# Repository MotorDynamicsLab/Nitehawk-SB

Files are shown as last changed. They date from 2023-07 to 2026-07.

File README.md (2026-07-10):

# Nitehawk-SB

This is the repo for Nitehawk-SB v1. The information for the updated version can be found here https://github.com/MotorDynamicsLab/Nitehawk-SB-V2.

Nitehawk is a toolhead PCB with a RP2040 MCU, TMC2209, Accelerometer all integrated into one board. The form factor is based on HartK’s two piece stealthburner toolhead PCB but with some minor changes. 

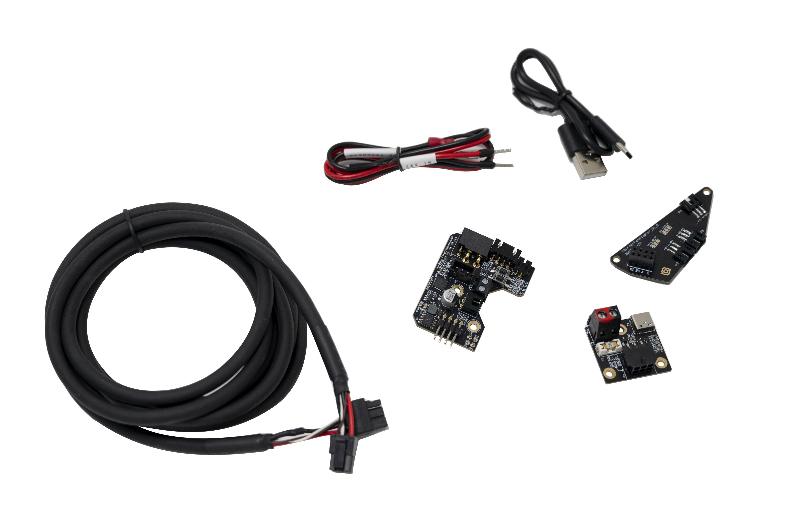
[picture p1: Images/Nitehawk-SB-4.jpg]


## Features

- Greatly simplified wiring, a single wire runs through the drag chain or in an umbilical setup. No additional breakout cables needed.
- Based on Klipper USB, no additional hardware or software setup compared to CAN.
- Tachometer enabled fan ports (PCF and HEF), allowing for fan speed detection.
- Integrated accelerometer for convenient input-shaping.

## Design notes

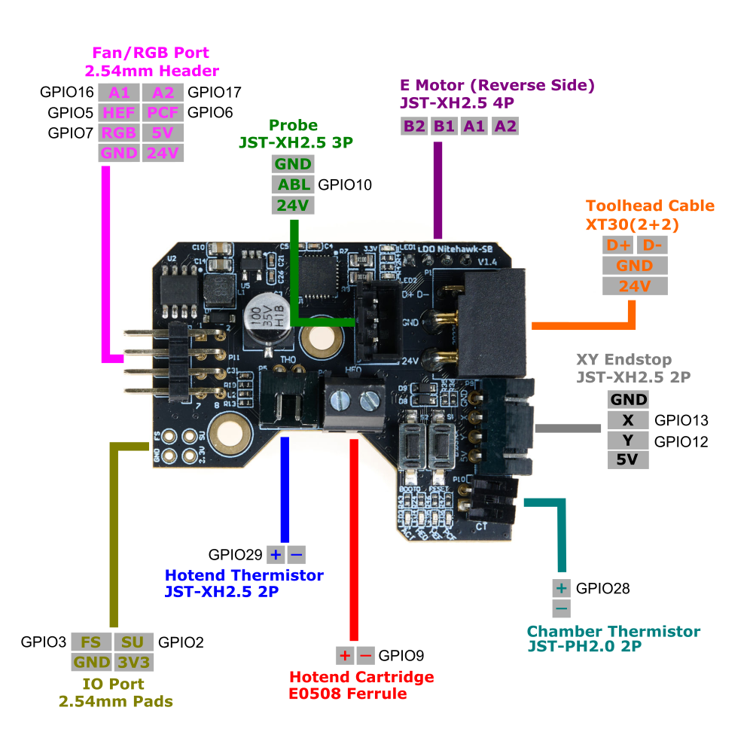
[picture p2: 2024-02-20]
Images/nhsb_pcb_pinout.png

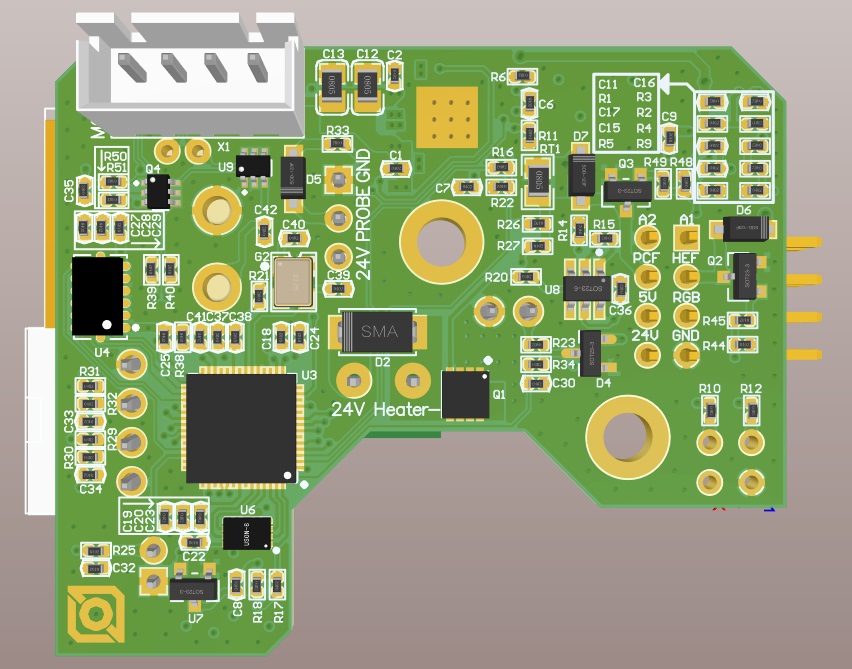
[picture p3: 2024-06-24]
Hardware/Nitehawk-SB_V1.5_3D Layout Bottom.jpg

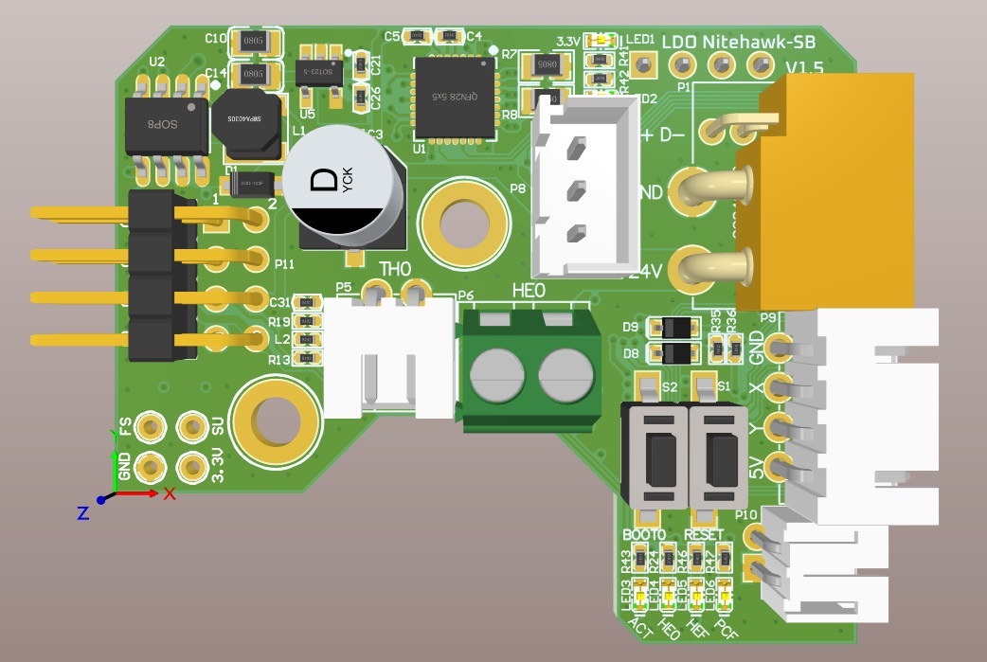
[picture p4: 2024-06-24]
Hardware/Nitehawk-SB_V1.5_3D Layout Top.jpg

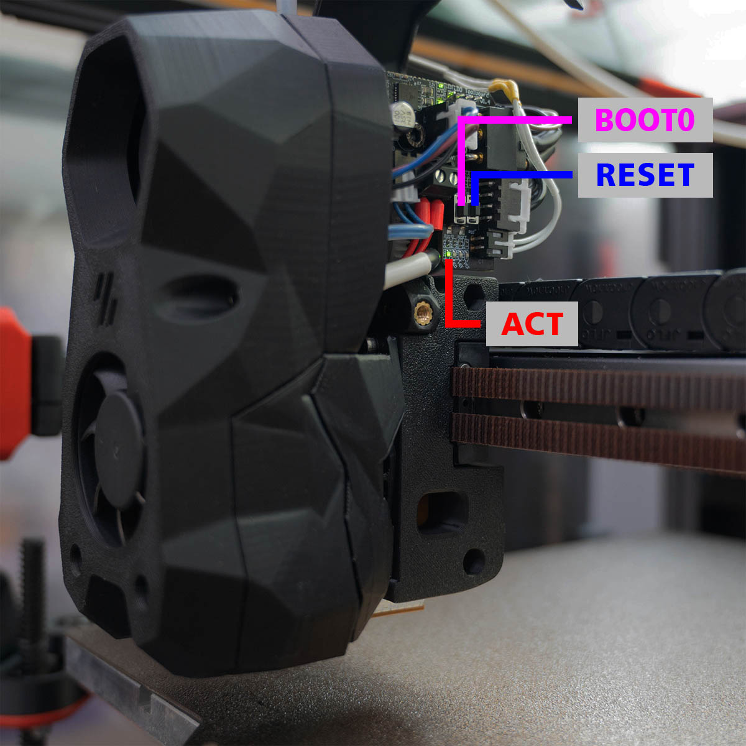
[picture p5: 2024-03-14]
Images/nitehawk_buttons.jpg

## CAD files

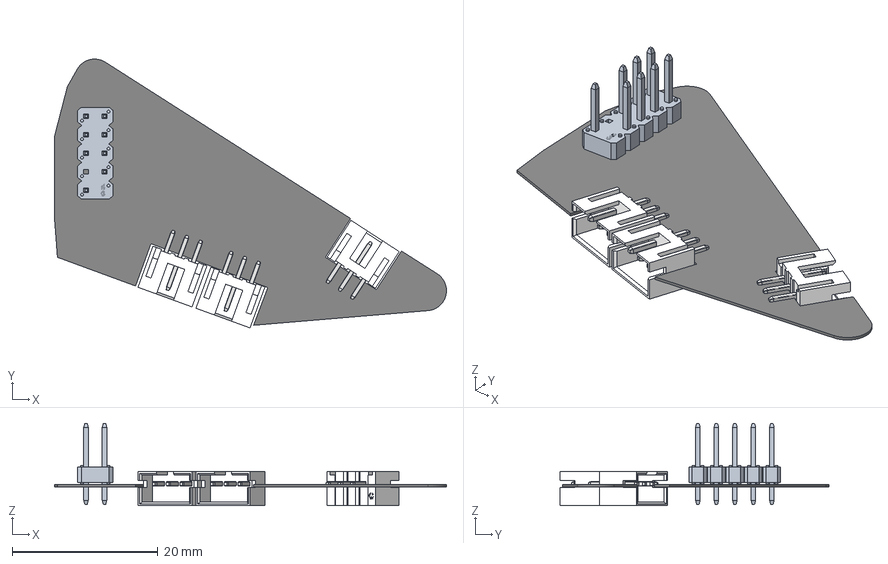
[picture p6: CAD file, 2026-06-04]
CAD/StealthBurner_Fan_Adapter_PCB.step
53.8 x 36.9 x 11.3 mm
PH2.0-LI-ӽ½ x 9
PH2.0-LI-3P x 3
LOGOԲ0.25 x 3
SBurnerFanAdapter 1.2.1
SBurnerFanAdapter_PCB

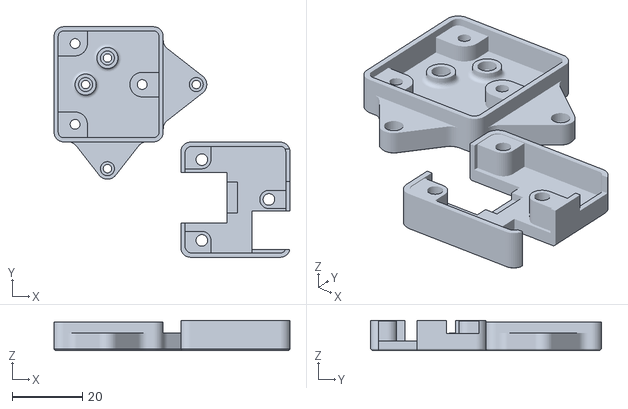
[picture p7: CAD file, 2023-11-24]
STLs/usb_adapter_mount.stl
67.2 x 65.6 x 8.60

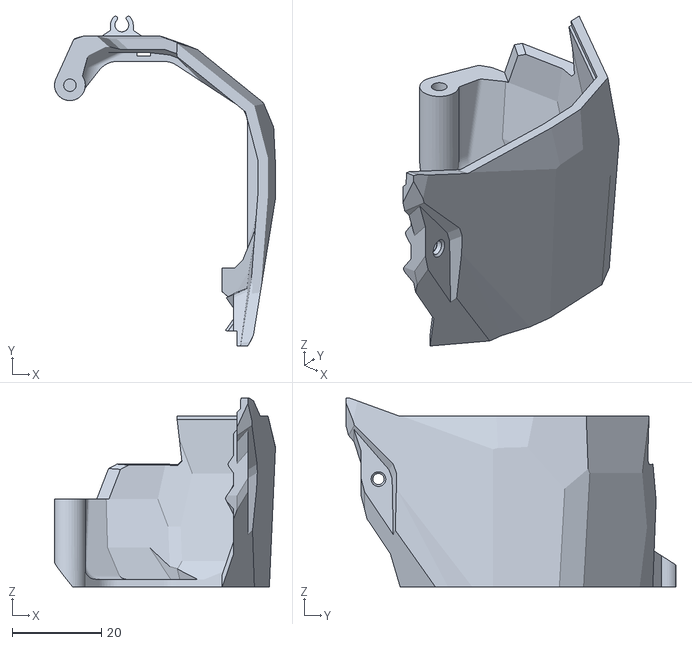
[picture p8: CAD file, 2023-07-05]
STLs/cw2_captive_pcb_cover.stl
49.5 x 73.8 x 42.2

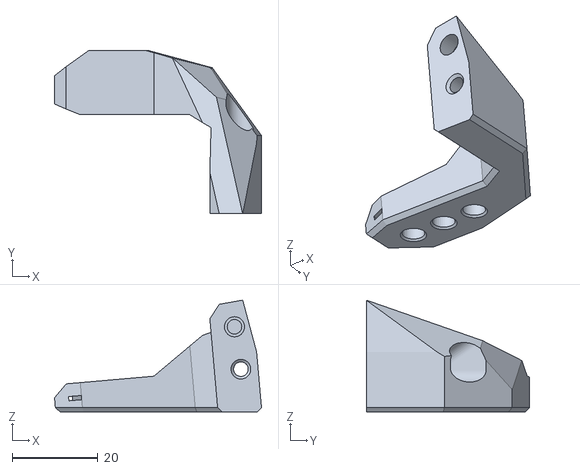
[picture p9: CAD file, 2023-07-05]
STLs/cw2_chain_anchor_tilted.stl
48.3 x 38.1 x 26.0

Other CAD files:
STLs/CW2 Captive PCB Cover.f3d
STLs/CW2 Chain Anchor Tilted.f3d
STLs/USB Adapter Mount.f3d

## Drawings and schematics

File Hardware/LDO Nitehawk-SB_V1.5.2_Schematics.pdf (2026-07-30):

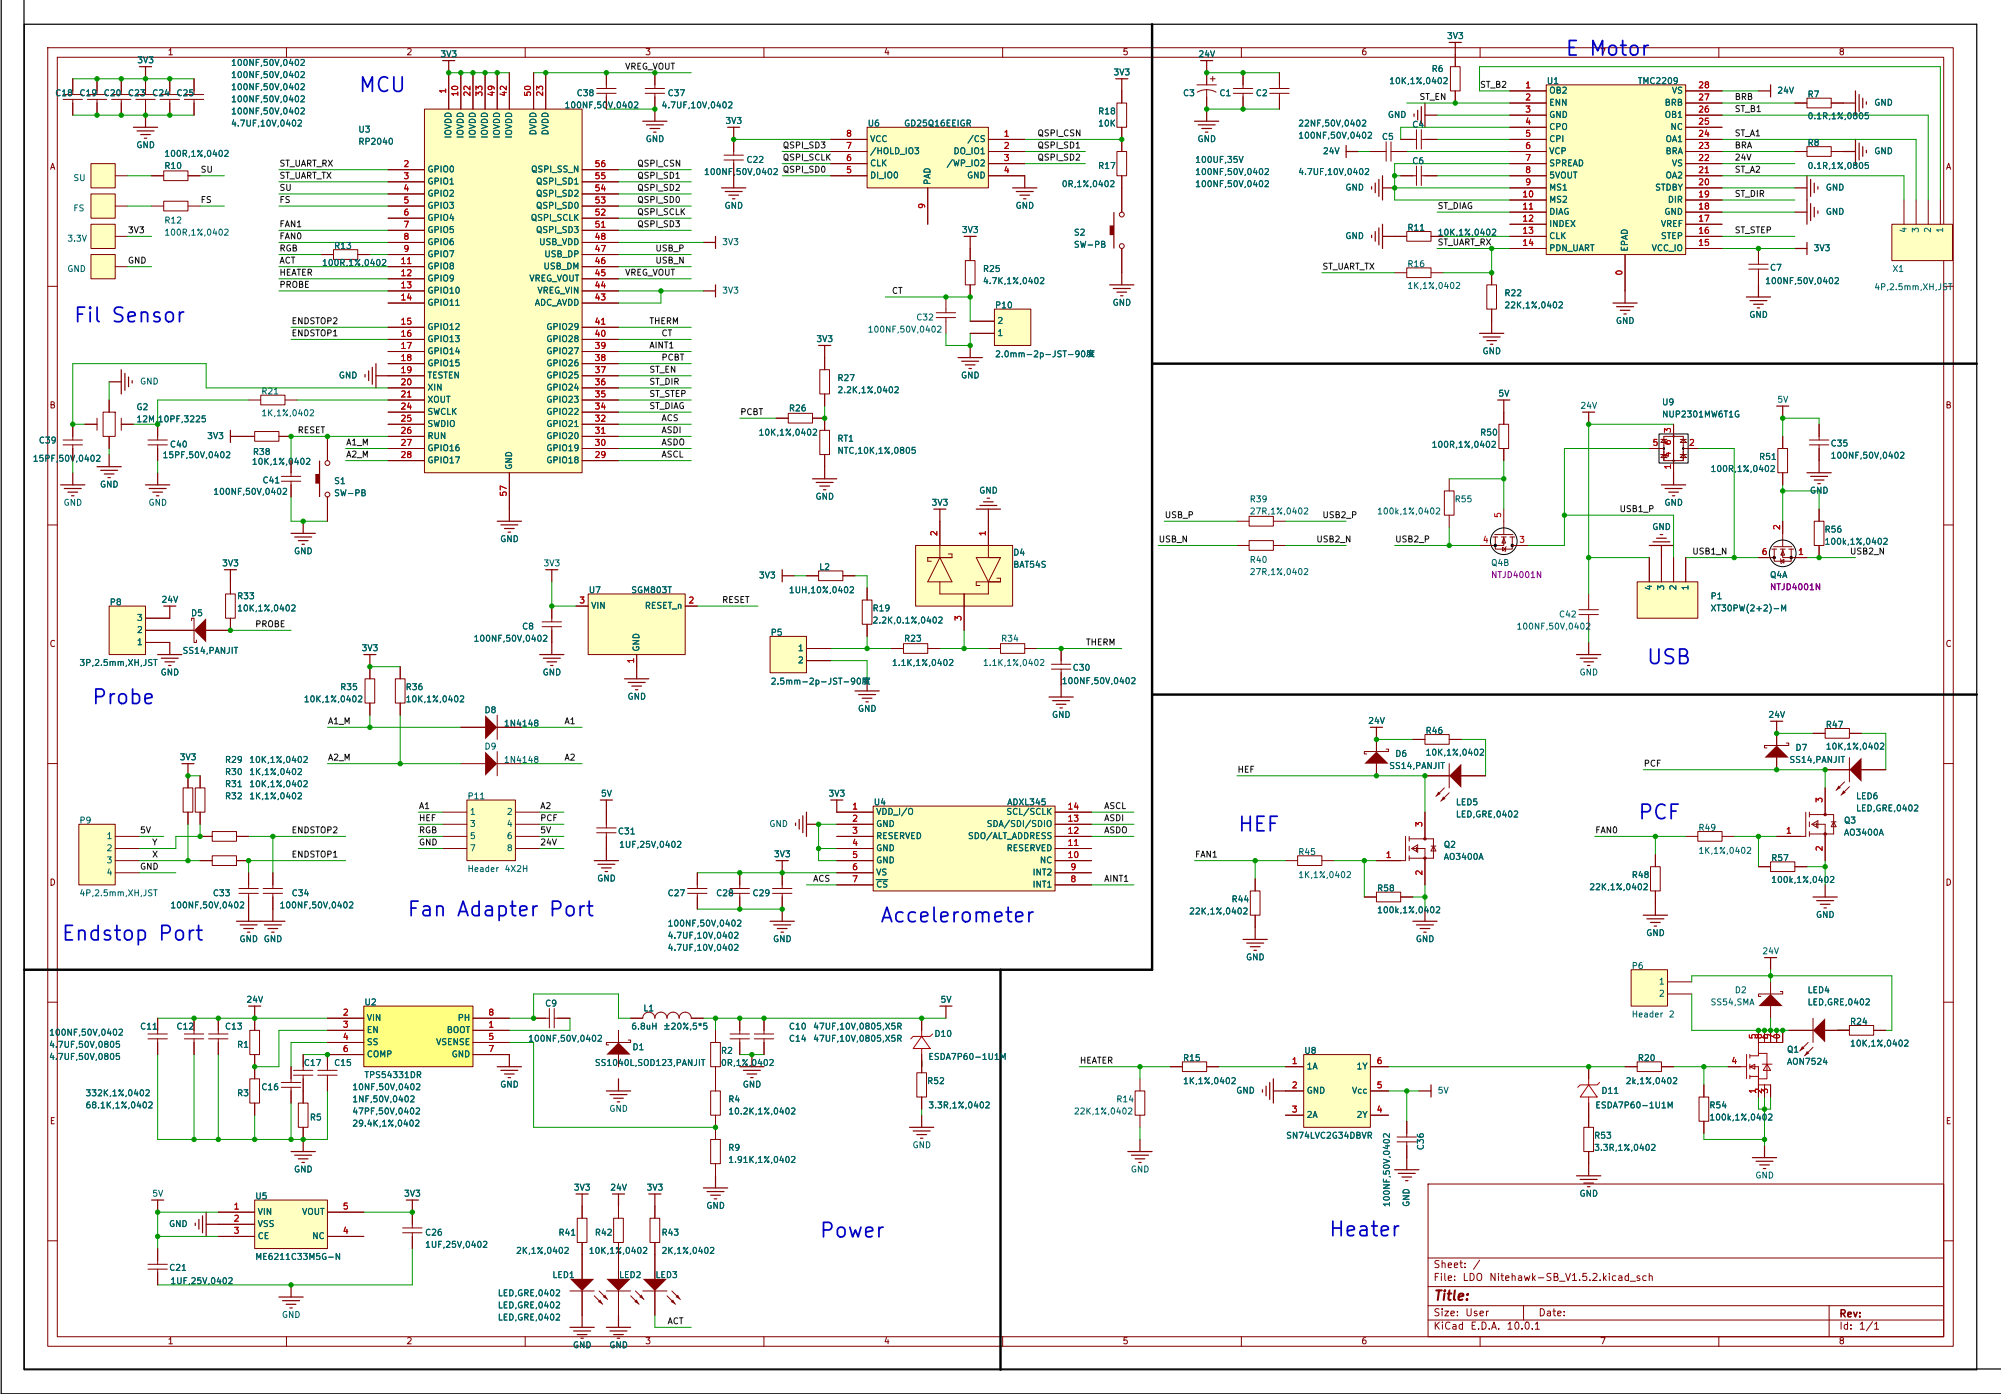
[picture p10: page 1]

RESERVED OR EXPRESS OR IMPLIED WARANTEE GIVEN. Fil Sensor

ENN 2 GND 3 CPO 4 CPI 5 | 26 BRB

APPROVALS PCB DWG: CHK: PCF

Size: User | Rev:
KiCad E.D.A. 10.0.1 | Id: 1/1

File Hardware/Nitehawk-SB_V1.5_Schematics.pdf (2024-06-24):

VCC_IO | 15 STEP | 16 VREF | 17 GND | 18 DIR | 19 STDBY | 20 OA2 | 21 VS | 22 BRA | 23 OA1 | 24 NC | 25 OB1 | 26 BRB | 27 VS | 28

# E Motor

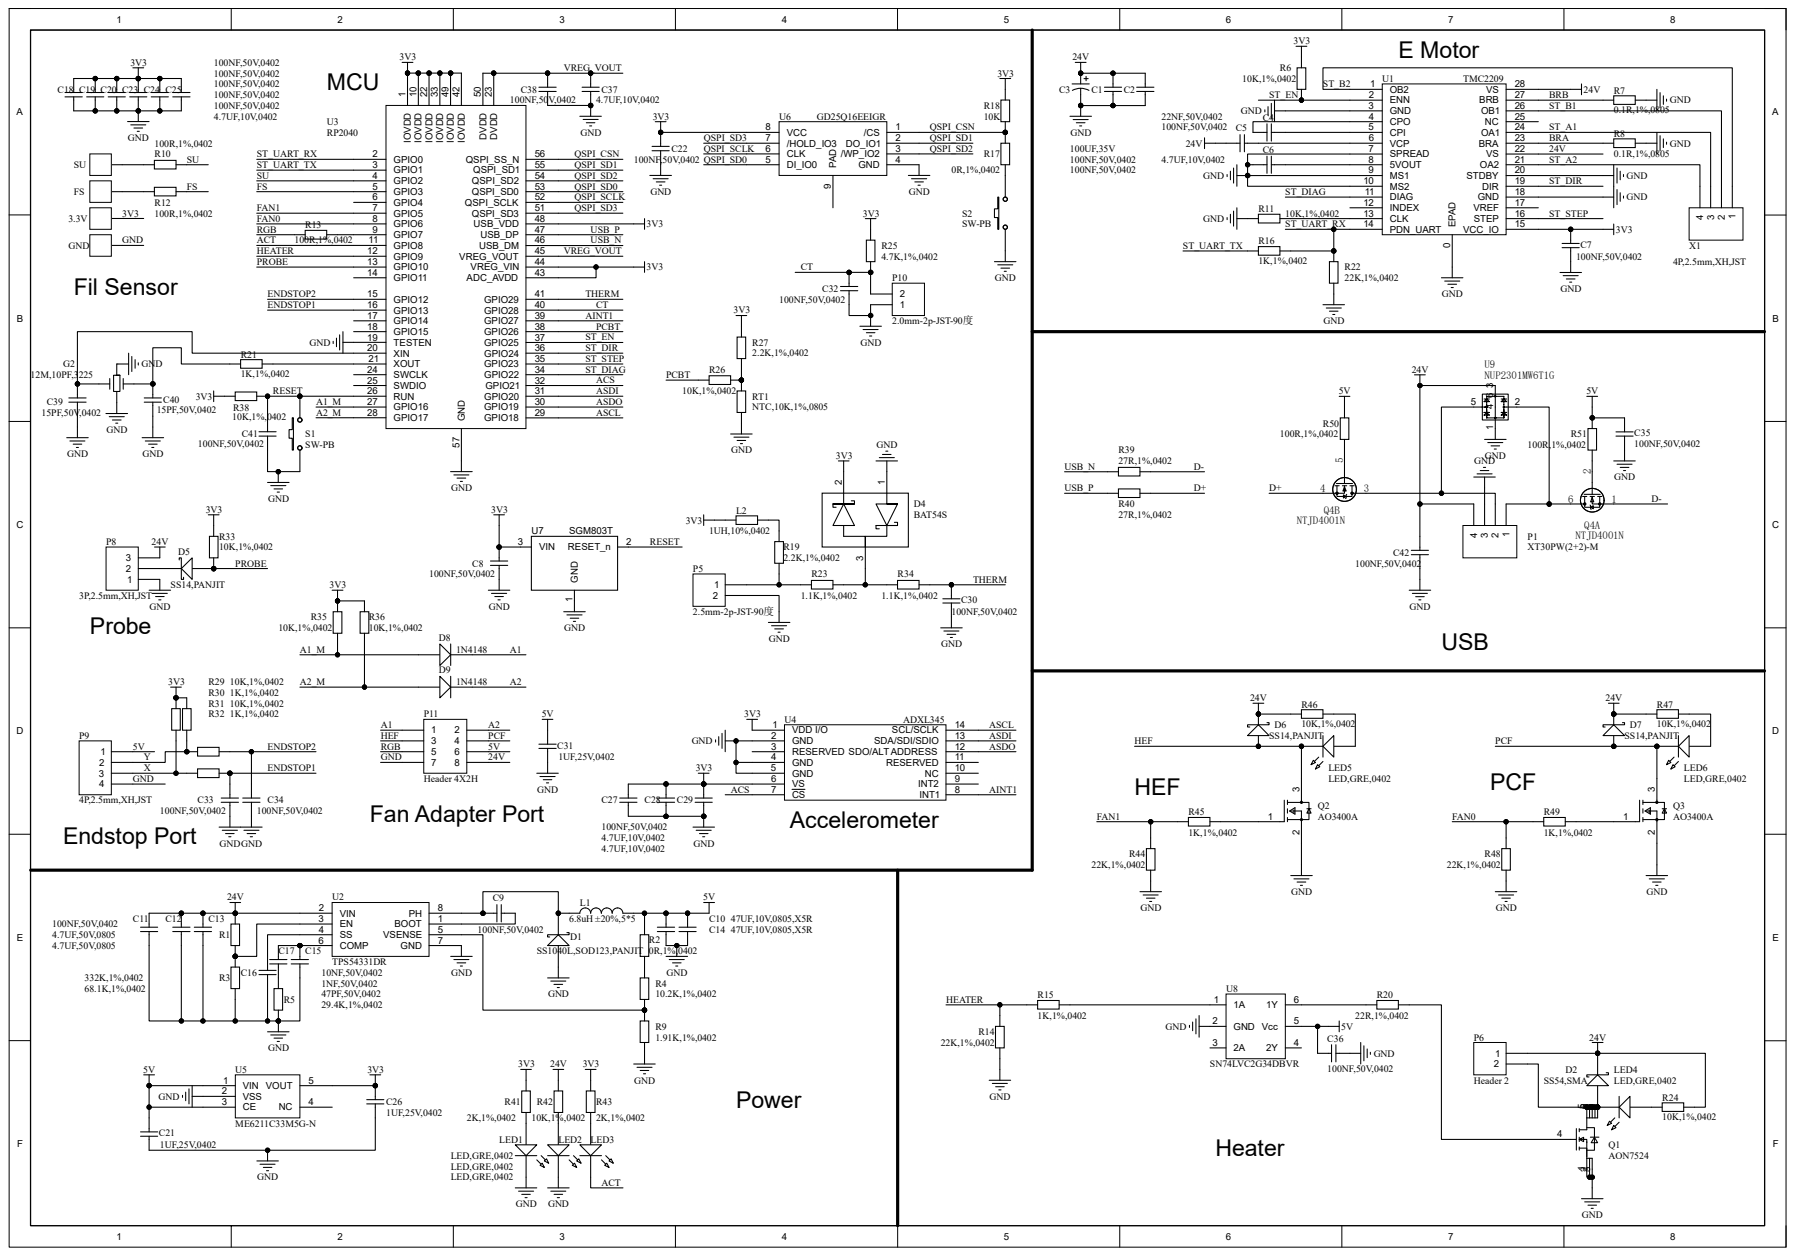
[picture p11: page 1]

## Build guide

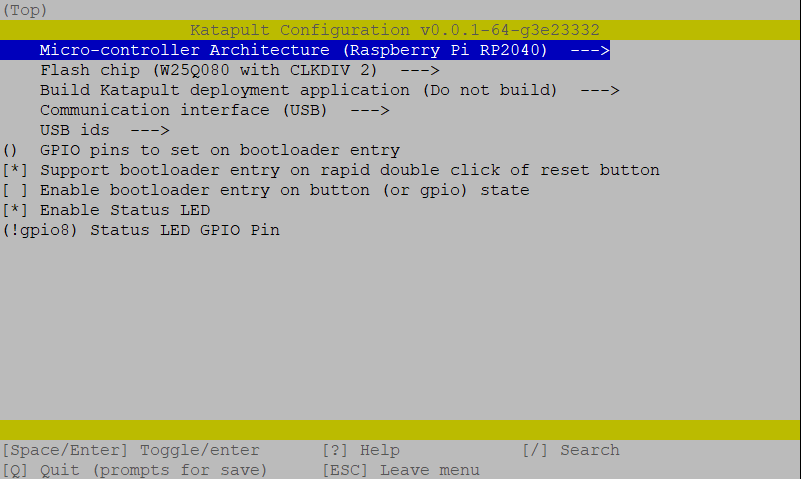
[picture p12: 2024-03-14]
Images/katapult_make_settings.png

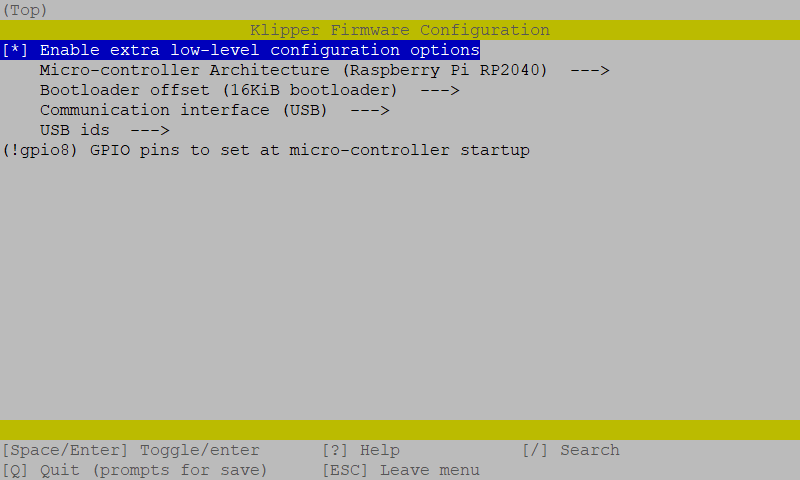
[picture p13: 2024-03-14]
Images/klipper_make_settings.png

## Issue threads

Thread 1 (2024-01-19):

Probe diode

YoungHillionaire, 2024-01-19:
Does it have bat diode connected to probe port?

jwyse, 2024-02-18:
There is a Schottky diode (SS14) on probe pin 2: [schematic](https://github.com/MotorDynamicsLab/Nitehawk-SB/blob/master/Hardware/Nitehawk-SB%20V1.4%20Schematics.pdf).

cneshi, 2024-02-20:
Yes there is a diode so the probe pin 2 is 24V tolerant

Closed 2024-02-20.

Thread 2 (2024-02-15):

gpio28/chamber thermistor shows wrong connector type

doomcrewinc, 2024-02-15:
In the images:
/nhsb_pcb_pinout.png
/nhsb_pcb_pinout.svg
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

The Chamber Thermistor / GPIO28 lists the connector type as "JST-XH2.5"

When I installed the board, I had to use a "JST-PH2" connector which was included in the kit.

This could cause confusion for people if they expect the Chamber Thermistor to directly plug in to the new Nitehawk board.

cneshi, 2024-02-20:
Thank you for raising this issue, I have fixed it in this commit: 5c038ff8833832aaf801ac7cedaf7245eb51493e

Closed 2024-02-20.

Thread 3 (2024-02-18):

MCU not recognised

andycrane, 2024-02-18:
New printer build. Both the control board and NHK mcu id's seen. Klipper update using LDO doc instructions (Klipper Make Upload) performed. MCU is now not seen.

Hard reboot, still no NHK mcu present. Physical connections checked. Controller mcu is still present.

Have I bricked the board? If so, are there instructions for a fresh Klipper install to the board?

Closed 2024-08-06.

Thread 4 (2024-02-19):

Zero RPM when part cooling fan above 90%.

z00mantwo, 2024-02-19:
Is there an RPM limit for readings from the Nitehawk board? My part cooling fan reads RPM when below 90% above that it reads 0 rpm. The fan is capable of 5,500 RPM.

Fan is
https://www.digikey.com/en/products/detail/delta-electronics/BFB0524H-R00/5799880

cneshi, 2024-02-20:
that is a very strange issue, I wonder if it has to do with the `tachometer_poll_interval` Can you tweak this value to see if anything changes Here is the reference for it: https://www.klipper3d.org/Config_Reference.html#fan

z00mantwo, 2024-02-20:
That didn't make a difference. I think maybe the fan does not really give RPM. Instead it gives a "running" signal. See

https://www.delta-fan.com/Download/Spec/BFB0524H-R00.pdf

Page 8. At least I think that is what it is saying. I may be wrong.

z00mantwo, 2024-02-20:
I tried this fan and RPM seems to be reading properly

https://www.digikey.com/en/products/detail/cui-devices/CBM-5015BF-055-391-20/19524615

cneshi, 2024-02-22:
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

you are right, according to the datasheet this delta fan only gives a simple high/low signal indicating whether it is running or not.

Closed 2024-02-22.

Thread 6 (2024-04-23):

CAD files missing

YoungHillionaire, 2024-04-23:
CAD files missing for the Nitehawk
To be able to make mounts for the usb adapter

camerony, 2024-08-06:
CAD file are present.

Closed 2024-08-06.

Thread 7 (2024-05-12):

Did we forget the files/specs/info on the usb board?

BlackNet, 2024-05-12:
The board this product ships with is labeled LDO motors USB adapter v1.4.  Yet I see no mention of it anywhere on this repo.  Is that an oversite or intentional?

camerony, 2024-08-06:
All files are there.

Closed 2024-08-06.

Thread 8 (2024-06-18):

GSTAT 00000001

aGAMEki, 2024-06-18:
Hello There,

I Have a Problem für the Nitehawk and Galileo 2 Extruder. Since i have Built the Galileo 2 Extruder with the Nitehawk sometimes the Nitehawk shows the GSTAT Issue and the Print broke up.

"After I have rerouted all the cables, tightened all the screws, and checked all the connections, it ran for some time and then there were several failures during printing again. What could be the cause? Is the controller getting too hot in the Stealthburner? I don't have these problems with my Switchwire, only with my Voron 2.4."

camerony, 2024-08-06:
Please ask in Discord, if you're still having problems.

Closed 2024-08-06.

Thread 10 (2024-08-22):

Lost communication with MCU 'nhk' Nitehawk keeps disconnecting

KastenTaco, 2024-08-22:
My Nitehawk keeps disconnecting about an hour into each print.
At this point I have checked all connectors multiple times, made sure things don't overheat (47C max temperature), re-flashed Klipper, replaced the RPI, and tried a new USB cable.
All to no avail. It seems somewhat random, and I am at a loss.

Are there any known hardware or quality issues with the board itself? This is the only component I can not test and verify.

R-yang1, 2024-08-23:
Hi, this is Rebecca from LDO team.
Could you please send a email to support@ldomotors.com with a picture of wiring and the klippy.log?

Thanks.

patlap13, 2024-12-24:
I had the same issue. a soon as toouch yhe cable I got the error

Daisy1819, 2024-12-26:
> I had the same issue. a soon as toouch yhe cable I got the error

Hi, Could u write an email to describe your problem to our support account, it should be support@ldomotors.com.

patlap13, 2024-12-26:
I found the problem actually

The connector is getting looser and Connor  stay un place

I’m designing a retainer fie the Galileo extruder.

Sent from my iPad

On Dec 25, 2024, at 20:43, Daisy1819 ***@***.***> wrote:

I had the same issue. a soon as toouch yhe cable I got the error

Hi, Could u write an email to describe your problem to our support account, it should be ***@***.******@***.***>.

—
Reply to this email directly, view it on GitHub<https://github.com/MotorDynamicsLab/Nitehawk-SB/issues/10#issuecomment-2562064735>, or unsubscribe<https://github.com/notifications/unsubscribe-auth/ABIAT7GWZNNJTP6RPXSZOA32HNNK5AVCNFSM6AAAAABM6I747CVHI2DSMVQWIX3LMV43OSLTON2WKQ3PNVWWK3TUHMZDKNRSGA3DINZTGU>.
You are receiving this because you commented.Message ID: ***@***.***>

Daisy1819, 2024-12-27:
Glad to hear that. If the connector is loose, i recommend u can use a tweezers to enlarge the connect ports, it may help.

Best regards,
Daisy

***@***.***

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

Daisy1819, 2024-12-27:
like the photo.

***@***.***

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

JJayzX, 2025-08-15:
I've been getting this issue intermittently with new board but is now suddenly constant. It is not the connection as it has happened while in heating phase, so no movement, and no matter what I move around does not cause it to disconnect. Mainboard is Manta M8P v2 with RPi 5 and all the software is updated to today.

z00mantwo, 2025-08-15:
I had a similar problem. Switching the Nitehawk to the USB 2.0 port on my Raspberry Pi 4b with the other USB 2.0 port empty has fixed it for me.

z00mantwo, 2025-09-04:
Try adding

usbcore.autosuspend=-1

to the end of the line in your /boot/cmdline.txt or /boot/firmware/cmdline.txt depending on the version of the OS you have.

Has to be at the end of the single line that is in the cmdline.txt. With a space before it. This will prevent the OS from trying to save power by turning off USB devices. It has helped clear up issues with long prints for me. Hopefully this will help.

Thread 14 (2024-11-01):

Can this board work with a 12v system ?

glennpierce, 2024-11-01:
Can this board work with a 12v system ?
The regulator seems to to accept a wide input range my over concern is the increased current . Can the USB cable cope ?
Any other possible issues ?

gyscos, 2024-11-04:
The doc mentions the USB cable is rated for 120w (at 24V), which would mean ~5A. If you're running 12V at 5A, the cable itself _should_ be fine. This _may_ be enough for a 40W hotend and a 1A extruder.

The electrical specifications for the board seem to indicate a min voltage of 20V though: https://docs.ldomotors.com/en/Toolboard/nitehawk-sb#electrical-specifications

glennpierce, 2024-11-04:
Thanks. I think it possibly could if changing the resistors for the regulator but its probably not worth the hassle or risk.

Closed 2024-11-04.

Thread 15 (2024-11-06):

What are the FS and SU pins for?

gyscos, 2024-11-06:
In the IO ports, there are 2 pins connected to GPIO2 and GPIO3: `FS` and `SU`.

Does `FS` mean "Filament Sensor"?
What does `SU` stand for?

Can they be used safely for that?

gramresearch, 2024-11-15:
GPIO is literally, general purpose IO, use it for whatever you want. FS is for filament sensor and that's what I use it for.  I'm not sure what SU was supposed to signify, but both are mere suggestions of what they can be used for.

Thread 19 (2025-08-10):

Nitehawk SB not recognized on Rpi 5 usb

ecksa, 2025-08-10:
I recently upgraded my rpi3b+ to a rpi 5. Nitehawk works without issue on rpi3 but it will not recognize it on rpi5. I've tried in boot mode and everything, it's like its not plugged in (i have checked the cable and made sure it was fully seated). Other usb devices are found no issue, just the nitehawk board. If i move the cable back to the rpi3 it finds it not problem, right away, so it's clearly not the NH board being burned out or something. I have tried to disable usb current limit. I am also using an official 5v 5a power supply for the pi.

z00mantwo, 2025-08-13:
From the Nitehawk, the Pi 5, or something else? I'm doing this upgrade myself soon.

ecksa, 2025-08-13:
[R7 Resistor Removal Guide.pdf](https://github.com/user-attachments/files/21764000/R7.Resistor.Removal.Guide.pdf)

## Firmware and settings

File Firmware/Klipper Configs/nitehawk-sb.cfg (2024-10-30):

# This file contains pin mappings for the LDO Nitehawk-SB Toolboard
# To use this config, the firmware should be compiled for the Raspberry Pi RP2040
# Make sure to include this config *at the end* of printer.cfg to overwrite the relevent sections

# See https://docs.ldomotors.com/en/voron/nitehawk-sb#firmware-setup-and-update
# For instructions on uploading/updating klipper firmware to the PCB

## LDO Nitehawk-SB Toolboard Partial Config

## *** THINGS TO CHANGE/CHECK: ***
## MCU paths                            [mcu] section
## Thermistor types                     [extruder] sections

## *MAKE SURE* to include this partial config file *AFTER* the main controller config. 
## This will ensure the relavent sections are overwritten by the pin mappings specified here.

[mcu nhk]
##  Obtain definition by "ls -l /dev/serial/by-id/" then unplug to verify
##--------------------------------------------------------------------
serial: /dev/serial/by-id/usb-Klipper_rp2040_E012345678900000-if00
restart_method: command
##--------------------------------------------------------------------

#####################################################################
#   Endstops
#####################################################################

## XES - Toolhead PCB
[stepper_x]
endstop_pin: nhk:gpio13

## YES - Toolhead PCB
[stepper_y]
endstop_pin: nhk:gpio12

#####################################################################
# 	Extruder
#####################################################################
[extruder]
step_pin: nhk:gpio23
dir_pin: nhk:gpio24
enable_pin: !nhk:gpio25
heater_pin: nhk:gpio9
sensor_pin: nhk:gpio29
pullup_resistor: 2200

[tmc2209 extruder]
sense_resistor: 0.100
uart_pin: nhk:gpio0
tx_pin: nhk:gpio1
interpolate: false
#run_current:         #recommend setting it below 0.7A.


#####################################################################
#   Fans
#####################################################################
## PCF
[fan]
pin: nhk:gpio6
#tachometer_pin: nhk:gpio17
#tachometer_ppr: 2

## HEF
[heater_fan hotend_fan]
pin: nhk:gpio5
tachometer_pin: nhk:gpio16
tachometer_ppr: 2

#####################################################################
# 	Probe
#####################################################################
## Probe Port
[probe]
pin: nhk:gpio10

#####################################################################
#   Lights
#####################################################################
##Stealthburner Headlights
[neopixel sb_leds]
pin: nhk:gpio7
chain_count: 3
color_order: GRBW
initial_RED: 0.0
initial_GREEN: 0.0
initial_BLUE: 1.0
initial_WHITE: 0.0

## PCB Activity Light
[output_pin act_led]
pin: !nhk:gpio8

#####################################################################
#   Accelerometer
#####################################################################
[adxl345]
cs_pin: nhk:gpio21
spi_software_sclk_pin: nhk:gpio18
spi_software_mosi_pin: nhk:gpio20
spi_software_miso_pin: nhk:gpio19

[resonance_tester]
accel_chip: adxl345
##--------------------------------------------------------------------
## Uncomment below for 250mm build
#probe_points:
#    125, 125, 20

## Uncomment below for 300mm build
#probe_points:
#    155, 155, 20

## Uncomment below for 350mm build
#probe_points:
#    175, 175, 20

##--------------------------------------------------------------------

#####################################################################
#   Thermistors
# #####################################################################
## External Chamber Thermistor Port
[temperature_sensor chamber_temp]
sensor_type: Generic 3950
sensor_pin: nhk:gpio28
min_temp: 0
max_temp: 100
gcode_id: chamber_th

[thermistor CMFB103F3950FANT]
temperature1: 0.0
resistance1: 32116.0
temperature2: 40.0
resistance2: 5309.0
temperature3: 80.0
resistance3: 1228.0

[temperature_sensor nh_temp]
## Nitehawk PCB Sensor
sensor_type: CMFB103F3950FANT
sensor_pin: nhk:gpio26
pullup_resistor: 2200
min_temp: 0
max_temp: 100
gcode_id: nh_th

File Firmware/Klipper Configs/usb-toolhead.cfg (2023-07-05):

# This file contains pin mappings for the LDO USB toolhead PCB.
# To use this config, the firmware should be compiled for the Raspberry Pi RP2040
# Make sure to include this config *at the end* of printer.cfg to overwrite the relevent sections

# See http://docs.ldomotors.com/en/voron/voron01/umb#compiling-and-uploading-firmware 
# For instructions on uploading/updating klipper firmware to the frame PCB

## LDO Toolhead Controller partial config

## *** THINGS TO CHANGE/CHECK: ***
## MCU paths                            [mcu] section
## Thermistor types                     [extruder] sections

## *MAKE SURE* to include this partial config file *AFTER* the main controller config. 
## This will ensure the relavent sections are overwritten by the picobilical mappings specified here.

[mcu pth]
##  Obtain definition by "ls -l /dev/serial/by-id/" then unplug to verify
##--------------------------------------------------------------------
serial: /dev/serial/by-id/usb-Klipper_rp2040_E6614864D3264037-if00
restart_method: command
##--------------------------------------------------------------------

#####################################################################
#   Endstops
#####################################################################

## XES - Toolhead PCB
## Overwrites the X endstop connection 
[stepper_x]
endstop_pin: pth:gpio13

## YES - Toolhead PCB
## Overwrites the Y endstop connection 
[stepper_y]
endstop_pin: pth:gpio12

#####################################################################
# 	Extruder
#####################################################################
[extruder]
step_pin: pth:gpio23
dir_pin: pth:gpio24
enable_pin: !pth:gpio25
heater_pin: pth:gpio9
sensor_pin: pth:gpio29
pullup_resistor: 2200

[tmc2209 extruder]
sense_resistor: 0.100
uart_pin: pth:gpio0
tx_pin: pth:gpio1
interpolate: false

#####################################################################
#   Fan Control
#####################################################################
[fan]
pin: pth:gpio6
#tachometer_pin: pth:gpio17
#tachometer_ppr: 2

[heater_fan hotend_fan]
pin: pth:gpio5
tachometer_pin: pth:gpio16
tachometer_ppr: 2

#####################################################################
# 	Probe
#####################################################################
[probe]
pin: pth:gpio10

#####################################################################
#   Lights
#####################################################################
[neopixel headlight]
pin: pth:gpio7

[output_pin act_led]
pin: !pth:gpio8

#####################################################################
#   Accelerometer
#####################################################################
[adxl345]
cs_pin: pth:gpio21
spi_software_sclk_pin: pth:gpio18
spi_software_mosi_pin: pth:gpio20
spi_software_miso_pin: pth:gpio19

[resonance_tester]
accel_chip: adxl345
probe_points:
    175, 175, 20


#####################################################################
#   TH
# #####################################################################
[temperature_sensor chamber_temp]
## Chamber Temperature - T1
sensor_type: Generic 3950
sensor_pin: pth:gpio28
pullup_resistor: 2200
min_temp: 0
max_temp: 100
gcode_id: chamber_th

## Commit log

2023-06-14 add klipper config and printed parts
    [CW2 Captive PCB Cover.f3d, CW2 Chain Anchor Tilted.f3d, USB Adapter Mount.f3d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]
2023-06-14 add schematics
2023-07-05 add STL version of printed parts
    [cw2_captive_pcb_cover.stl, cw2_chain_anchor_tilted.stl, usb_adapter_mount.stl]
2023-07-05 temporarily change pullup resistor to 2k2
    [usb-toolhead.cfg]
2023-07-28 add tacho_macros.cfg
    [tacho_macros.cfg]
2023-07-28 in tacho_macros.cfg, only spit out message if HEALTH_CHECK fails
    [tacho_macros.cfg]
2023-09-13 remove HEF_CHECK and related macros in tacho_macros.cfg
    [tacho_macros.cfg]
2023-11-10 update Nitehawk hardware schematics to newest version, add 3D model of PCB
2023-11-10 update klipper config to latest 1.4 HW
    [nitehawk.cfg]
2023-11-15 add klipper_make_settings.png
2023-11-24 update usb_adapter_mount.stl to newest version
    [USB Adapter Mount.f3d, usb_adapter_mount.stl]
2023-12-09 update nitehawk.cfg with correct PCB thermistor settings
    [nitehawk.cfg]
2024-01-02 update link to firmware instructions in the header
    [nitehawk-sb.cfg]
2024-02-20 fix incorrect connector label for CT in nhsb_pcb_pinout diagram
2024-02-23 add schematics for USB adapter
2024-03-14 add nitehawk_buttons.jpg and katapult_make_settings.png, update klipper_make_settings.png
2024-06-25 fix duplicate gcode_id issue in line 138 (duplicate of line 121)
    [nitehawk-sb.cfg]
2024-10-18 Add current configuration
    [nitehawk-sb.cfg]
2026-06-04 added 3d model of fan adapter and usb adapter pcb
    [StealthBurner_Fan_Adapter_PCB.step]
2026-07-30 Upload Nitehawk SB V1.5.2 Schematics
2026-11-11 updated fan board
2026-11-13 Add CW2.5 captive screw PCB cover
